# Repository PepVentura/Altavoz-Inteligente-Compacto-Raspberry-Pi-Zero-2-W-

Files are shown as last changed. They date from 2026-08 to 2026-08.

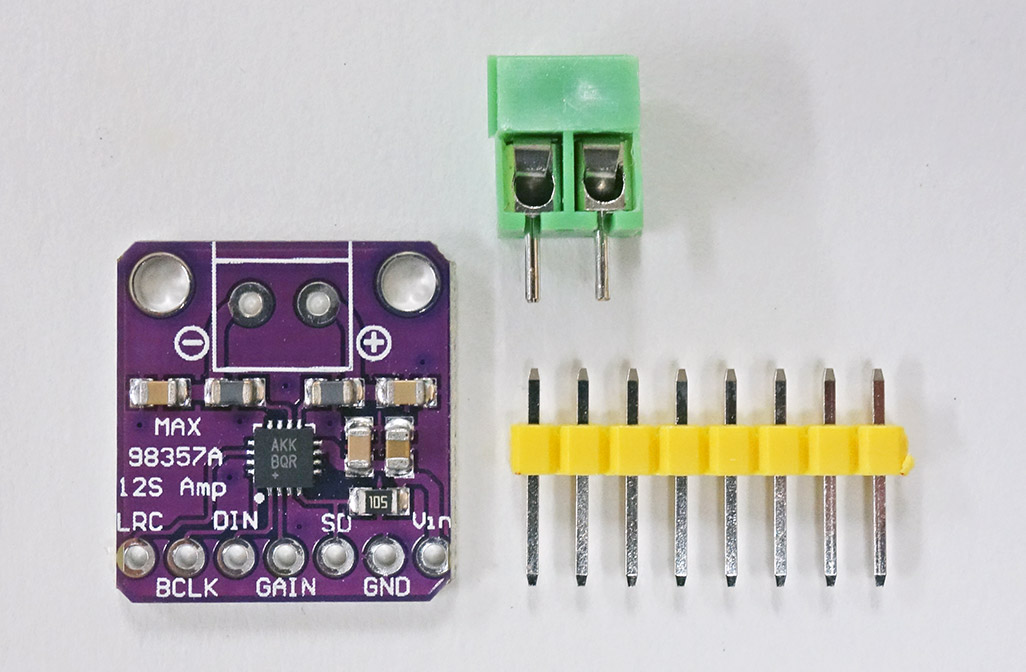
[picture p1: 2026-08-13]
Documents/max98357a i2s dac.jpg

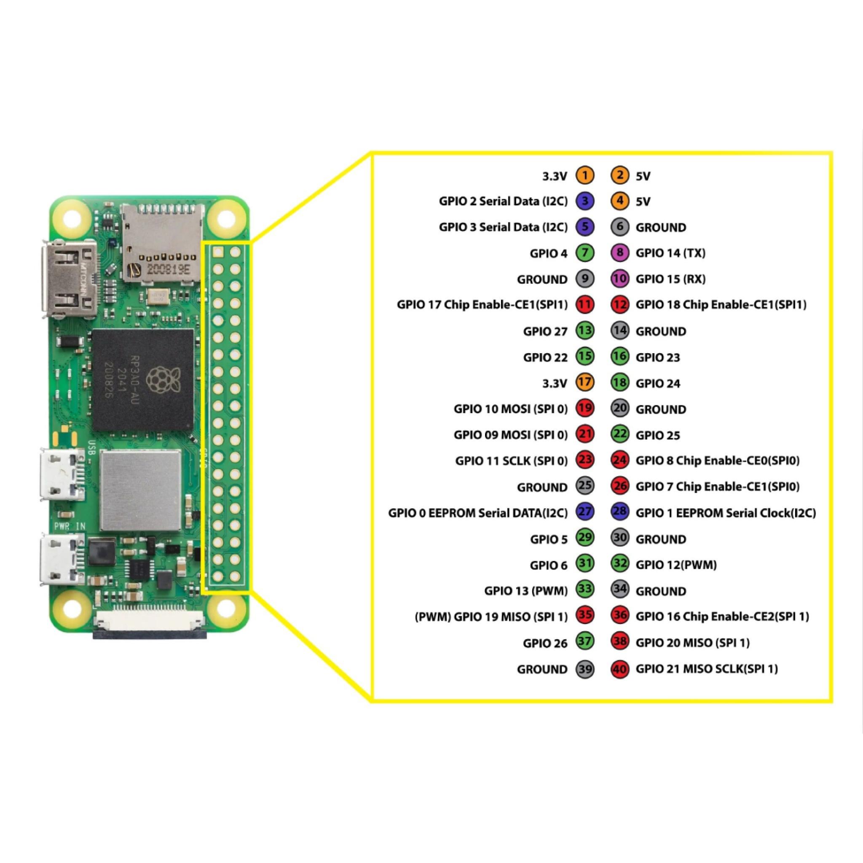
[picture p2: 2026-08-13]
Documents/placa-sbc-rpi-raspberry-pi-zero-w-2-2921-8204.jpg

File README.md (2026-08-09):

# Proyecto 1: Altavoz Inteligente Compacto (Raspberry Pi Zero 2 W)

Fase actual: Pruebas de concepto y desarrollo base.

## Hardware Utilizado:
- SBC: Raspberry Pi Zero 2 W
- Driver: Dayton Audio DMA45-4 (1.8")
- DAC/Amp: MAX98357A I2S
- LEDs: WS2812B Neopixel
- Carcasa: Búho Robotizado (Tamaño compacto)

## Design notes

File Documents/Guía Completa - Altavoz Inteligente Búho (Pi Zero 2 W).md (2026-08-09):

Guía Completa de Proyecto: Altavoz Inteligente Búho (Raspberry Pi Zero 2 W)
1. Visión General del Proyecto
Este proyecto consiste en la creación de un altavoz inteligente con diseño mecatrónico en forma de búho robotizado. Utiliza una Raspberry Pi Zero 2 W como unidad central de procesamiento, integración de audio digital I2S, anillos de LEDs WS2812B (Neopixel) para los ojos e integración con la API de Gemini para la interacción por voz.
Componente
Especificación / Modelo
Función
Cerebro
Raspberry Pi Zero 2 W
Procesamiento de voz local, conexión a la API de Gemini y control de periféricos.
Altavoz
Dayton Audio DMA45-4 (1.8", 4 Ω)
Reproducción de sonido de alta fidelidad en el cuerpo compacto.
Amplificador / DAC
MAX98357A (I2S, 5V)
Conversión de audio digital desde GPIO a señal analógica de potencia.
Iluminación / Ojos
2x Anillos Neopixel WS2812B
Feedback visual del estado del asistente (escuchando, pensando, respondiendo).
Carcasa
Impresión 3D (PLA / PETG)
Diseño estanco en forma de búho con lentes difusoras traslúcidas.

2. Esquema de Conexiones GPIO
A continuación se detalla el patillaje de conexión entre la Raspberry Pi Zero 2 W, el amplificador I2S y los anillos de LEDs Neopixel:
Componente
Pin en Módulo
Pin Físico Raspberry Pi
Función GPIO
MAX98357A
LRC / LRCK
Pin 35
GPIO 19 (PCM_FS)
MAX98357A
BCLK
Pin 12
GPIO 18 (PCM_CLK)
MAX98357A
DIN
Pin 40
GPIO 21 (PCM_DOUT)
MAX98357A
VIN / GND
Pin 2 (5V) / Pin 6 (GND)
Alimentación principal
Neopixel WS2812B
DIN
Pin 33
GPIO 13 (PWM1)

3. Paso a Paso: Configuración del Sistema Operativo y Audio I2S
Paso 1: Grabado de la Tarjeta MicroSD
Usar Raspberry Pi Imager para instalar Raspberry Pi OS Lite (64-bit).
Configurar el Hostname a buho-smart.
Activar SSH e introducir credenciales de acceso.
Configurar la red Wi-Fi de 2.4 GHz.
Paso 2: Instalar Dependencias del Sistema
sudo apt update && sudo apt upgrade -y
sudo apt install -y python3-pip python3-venv git alsa-utils libasound2-dev
Paso 3: Habilitar Driver I2S en el Firmware
Editar el archivo de configuración: sudo nano /boot/firmware/config.txt
Desactivar audio integrado comentando: # dtparam=audio=on
Añadir los parámetros de soporte I2S al final del archivo:
dtparam=i2s=on
dtoverlay=max98357a
Reiniciar la Raspberry Pi: sudo reboot
Paso 4: Verificación de Audio
# Comprobar tarjeta detectada
aplay -l

# Probar salida de altavoz
speaker-test -c 2 -twav -l 1
4. Código de Control Visual para los Ojos Neopixel (Python)
Guardar el siguiente script en src/led_controller.py para gestionar los efectos luminosos de los ojos según el estado del asistente:
import time
import board
import neopixel

NUM_LEDS = 24
pixels = neopixel.NeoPixel(board.D13, NUM_LEDS, brightness=0.4, auto_write=False)

def modo_reposo():
    pixels.fill((0, 20, 50))
    pixels.show()

def modo_escuchando():
    pixels.fill((0, 255, 150))
    pixels.show()

def modo_pensando_gemini():
    for i in range(NUM_LEDS):
        pixels.fill((0, 0, 0))
        pixels[i] = (0, 200, 255)
        pixels[(i + 1) % NUM_LEDS] = (150, 0, 255)
        pixels.show()
        time.sleep(0.05)

if __name__ == "__main__":
    modo_pensando_gemini()
5. Parámetros de Impresión 3D para Lentes Difusoras
Material: PLA Transparente o PETG Clear.
Relleno (Infill): 0% (Hueco).
Perímetros / Paredes: 3 a 4 líneas.
Grosor de capa: 0.12 mm o 0.16 mm.
Temperatura: 5 °C a 10 °C por encima del estándar del filamento.

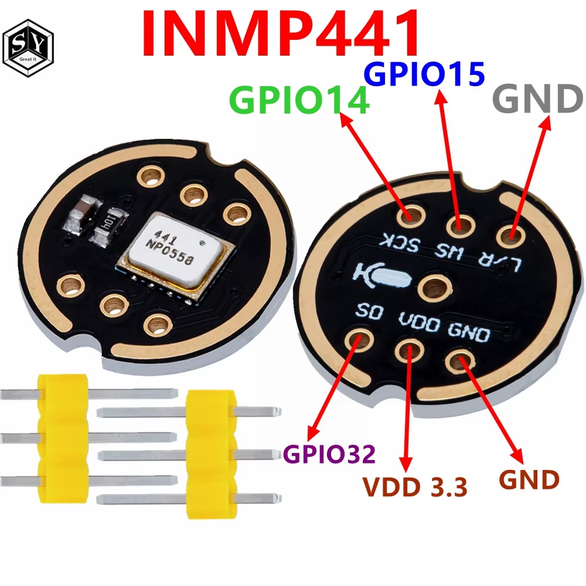
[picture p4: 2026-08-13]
Documents/Microfono inmp441.jpg

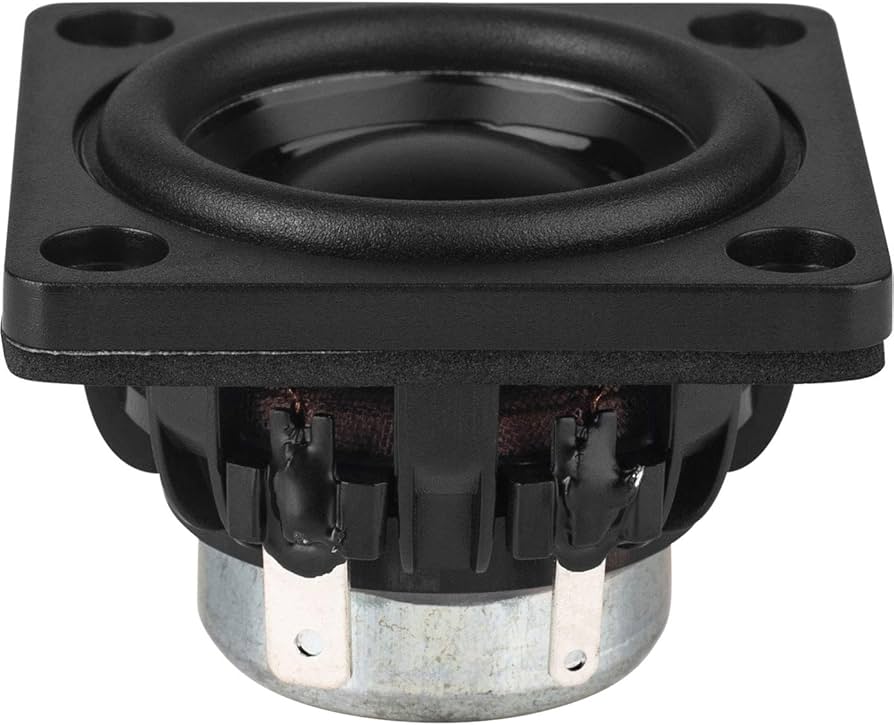
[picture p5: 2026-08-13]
Documents/Foto DMA45-4_.jpg

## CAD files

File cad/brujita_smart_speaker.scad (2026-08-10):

// =========================================================================
// CARCASA BRUJITA SMART SPEAKER v3 (Geometría Maciza + Paredes Selladas)
// =========================================================================

$fn = 80;

// Parámetros clave
speaker_d = 45.5;       // Diámetro Dayton DMA45-4
eye_led_d = 32.0;       // Diámetro Neopixel WS2812B
wall = 3.5;             // Grosor pared cámara acústica

// -------------------------------------------------------------------------
// 1. VOLUMEN EXTERIOR SÓLIDO (Sin vaciar)
// -------------------------------------------------------------------------
module exterior_solido() {
    // Base aplanada para impresión
    translate([0, 0, 2])
        cylinder(r=25, h=4, center=true);

    // Cuerpo / Vestido
    translate([0, 0, 40])
        scale([1.1, 1.0, 1.05])
            sphere(r=45);

    // Cabeza
    translate([0, 0, 95])
        scale([1.15, 1.0, 0.95])
            sphere(r=35);

    // Mofletes
    for(side = [-1, 1]) {
        translate([side * 18, -24, 85])
            sphere(r=13);
    }

    // Cuencas / Marcos destacados para los Ojos Neopixel
    for(side = [-1, 1]) {
        translate([side * 18, -25, 96])
            rotate([75, 0, side * -5])
                cylinder(d=eye_led_d + 8, h=12, center=true);
    }

    // Pelo rizado lateral
    for(side = [-1, 1]) {
        translate([side * 34, -5, 92]) sphere(r=11);
        translate([side * 35, -15, 82]) sphere(r=9.5);
    }

    // Nariz pequeña
    translate([0, -34, 89])
        sphere(r=4);

    // Cuello de encastre del sombrero
    translate([0, 0, 118])
        cylinder(r1=36, r2=24, h=12);
}

// -------------------------------------------------------------------------
// 2. CUERPO PRINCIPAL CON RECORES (Diferencia limpia)
// -------------------------------------------------------------------------
module brujita_cuerpo() {
    difference() {
        // Objeto base macizo
        exterior_solido();

        // --- VACIADO CÁMARA INTERIOR ESTANCA ---
        translate([0, 0, 40])
            scale([1.1 - (wall/45), 1.0 - (wall/45), 1.05 - (wall/45)])
                sphere(r=45 - wall);

        translate([0, 0, 95])
            scale([1.15 - (wall/35), 1.0 - (wall/35), 0.95 - (wall/35)])
                sphere(r=35 - wall);

        // Aplanar plano de la base por abajo
        translate([0, 0, -10])
            cube([120, 120, 20], center=true);

        // --- HUECO ALTAVOZ DAYTON DMA45-4 (FRONTAL) ---
        translate([0, -42, 35])
            rotate([90, 0, 0])
                cylinder(d=speaker_d, h=30, center=true);

        // --- ALOJAMIENTOS DE OJOS (CIEGOS CON FONDO) ---
        for(side = [-1, 1]) {
            translate([side * 18, -25, 96])
                rotate([75, 0, side * -5]) {
                    // Cajeado para insertar el anillo Neopixel (Solo 5mm de profundidad)
                    translate([0, 0, 3])
                        cylinder(d=eye_led_d, h=6, center=true);
                    
                    // Pequeño taladro central de 4mm para pasar únicamente los 3 cables (5V, GND, DATA)
                    cylinder(d=4, h=30, center=true);
                }
        }

        // --- BOCA DE ENTRADA SUPERIOR (Acceso a la Pi Zero 2 W) ---
        translate([0, 0, 122])
            cylinder(r=24, h=20, center=true);

        // --- PUERTO USB DE ALIMENTACIÓN (TRASERÍA) ---
        translate([0, 42, 8])
            cube([14, 20, 8], center=true);
    }
}

// -------------------------------------------------------------------------
// 3. TAPA SUPERIOR (Sombrero de Bruja Orgánico)
// -------------------------------------------------------------------------
module sombrero_tapa() {
    difference() {
        union() {
            // Ala con curva/caída suave
            scale([1, 1, 0.28])
                sphere(r=50);

            // Copa del sombrero con leve inclinación/pliegue
            translate([0, 0, 4])
                rotate([-7, 5, 0])
                    cylinder(r1=24, r2=2, h=55);
        }

        // Encastre macho inferior para encajar a presión en el cuello
        translate([0, 0, -18])
            cylinder(r=23.5, h=20);

        // Base plana del sombrero
        translate([0, 0, -20])
            cube([150, 150, 40], center=true);
    }
}

// Visualización en pantalla
brujita_cuerpo();

// Mover sombrero a un lado (X=90mm) para previsualizar/exportar por separado
translate([90, 0, 0])
    sombrero_tapa();
